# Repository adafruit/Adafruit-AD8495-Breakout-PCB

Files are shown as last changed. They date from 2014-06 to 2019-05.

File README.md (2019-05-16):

# PCB files for Adafruit Analog K-Type Thermocouple Amplifier AD8495 Breakout

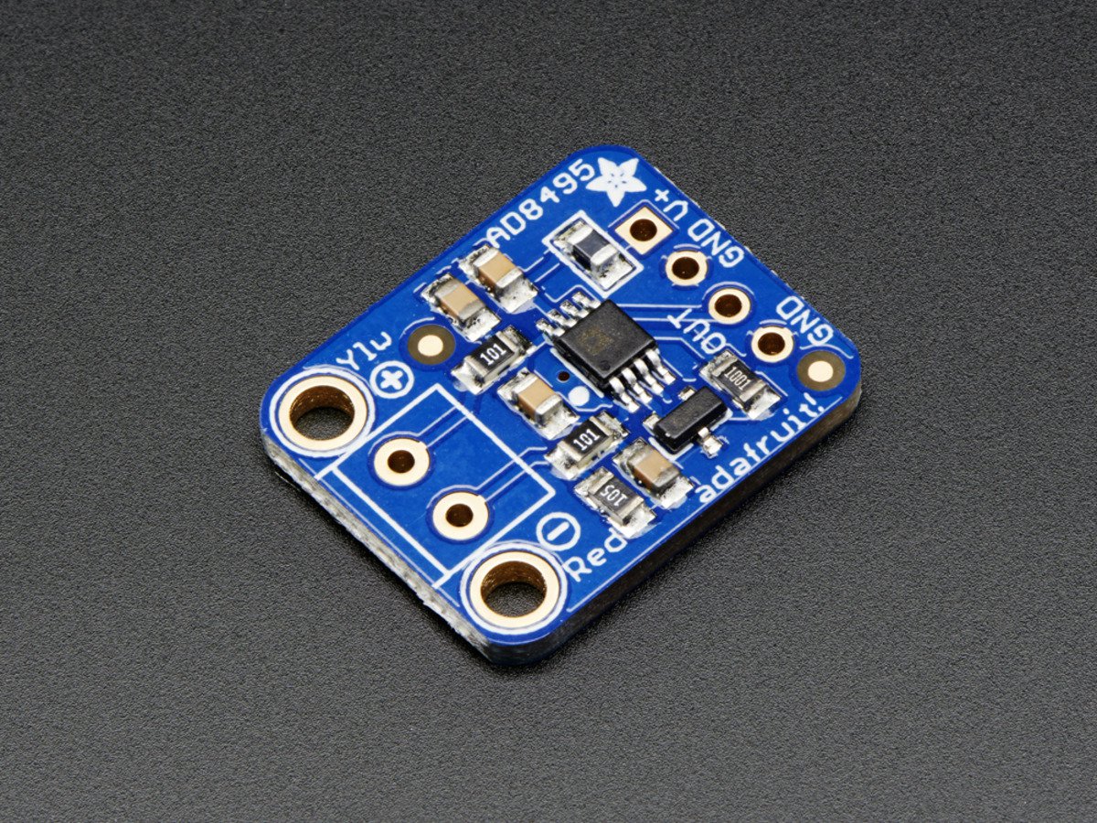
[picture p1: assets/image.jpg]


Thermocouples are very sensitive, requiring a good amplifier with a cold-compensation reference. We have a couple digital thermocouple amplifiers in the shop already from Maxim. Now we're happy to introduce an excellent analog-output amplifier. This is a very simple sensor to use, and if your microcontroller has analog input capability, you'll be ready to go really fast!

The AD8495 K-type thermocouple amplifier from Analog Devices is so easy to use, we documented the whole thing on the back of the tiny PCB. Power the board with 3-18VDC and measure the output voltage on the OUT pin. You can easily convert the voltage to temperature with the following equation: Temperature = (Vout - 1.25) / 0.005 V. So for example, if the voltage is 1.5VDC, the temperature is (1.5 - 1.25) / 0.005 = 50¡C

Each order comes with a 2 pin terminal block (for connecting to the thermocouple), a fully assembled PCB with the AD8495 + TLVH431 1.25V precision voltage reference, and pin header (to plug into any breadboard or perfboard). [Goes great with our 1m K-type thermocouple (not included)](http://www.adafruit.com/products/270). Not for use with any other kind of thermocouple, K type only!

- Works with any K type thermocouple
- Will not work with any other kind of thermocouple other than K type
- Easy to use analog output
- Temp range with 5V power: -250¡C to +750¡C output (0 to 5VDC) as long as the thermocouple can handle that range
- Temp range with 3.3V power: -250¡C to +410¡C output (0 to 3.3VDC) as long as the thermocouple can handle that range

__Note:__ The terminal blocks included with your product may be blue or black.

## License

Adafruit invests time and resources providing this open source design, 
please support Adafruit and open-source hardware by purchasing 
products from Adafruit!

Designed by Limor Fried/Ladyada for Adafruit Industries.
Creative Commons Attribution, Share-Alike license, check license.txt for more information
All text above must be included in any redistribution

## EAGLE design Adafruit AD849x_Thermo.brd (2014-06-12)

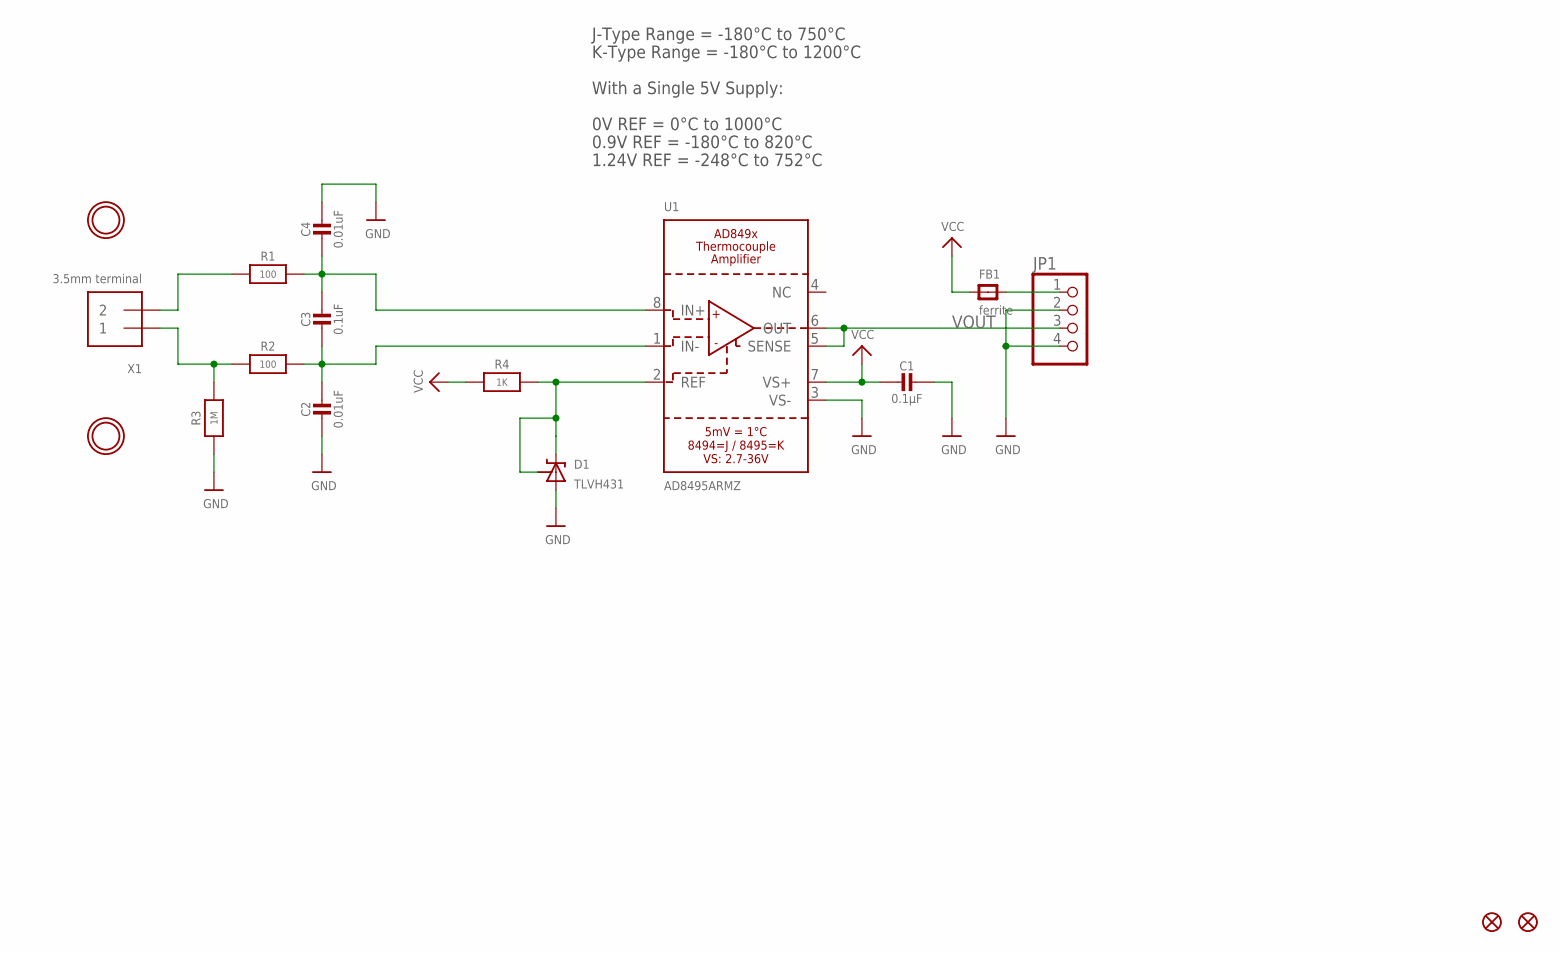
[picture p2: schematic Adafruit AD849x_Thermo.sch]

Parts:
C1: 0.1µF; 0805-NO
C2, C4: 0.01uF; 0805-NO
C3: 0.1uF; 0805-NO
D1: TLVH431; SOT23-R
FB1: ferrite; 0805
FID1, FID2: FIDUCIAL""; FIDUCIAL_1MM
JP1: HEADER-1X4ROUND; 1X04_ROUND
R1, R2: 100; 0805-NO
R3: 1M; 0805-NO
R4: 1K; 0805-NO
U1: AD8495ARMZ; MSOP8_0.65MM
U$11, U$12: MOUNTINGHOLE2.5; MOUNTINGHOLE_2.5_PLATED
X1: 3.5mm terminal; TERMBLOCK_1X2-3.5MM

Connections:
GND: C1.1, C2.2, C4.1, D1.3 (A), JP1.2, JP1.4, R3.1, U1.3 (VS-)
IN+: R1.1, X1.2
IN-: R2.1, R3.2, X1.1
unnamed: D1.1 (VREF), D1.2 (C), R4.2, U1.2 (REF)
unnamed: C3.1, C4.2, R1.2, U1.8 (IN+)
unnamed: C2.1, C3.2, R2.2, U1.1 (IN-)
unnamed: FB1.2, JP1.1
VCC: C1.2, FB1.1, R4.1, U1.7 (VS+)
VOUT: JP1.3, U1.5 (SENSE), U1.6 (OUT)

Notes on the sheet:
J-Type Range = -180°C to 750°C
K-Type Range = -180°C to 1200°C
With a Single 5V Supply:
1.24V REF = -248°C to 752°C
0.9V REF = -180°C to 820°C
0V REF = 0°C to 1000°C

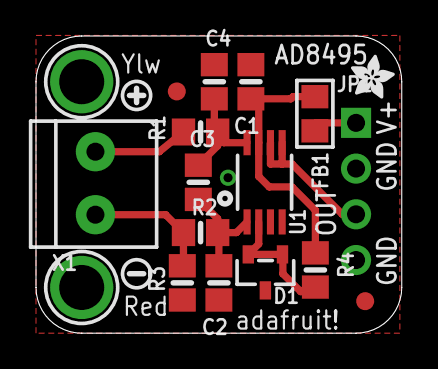
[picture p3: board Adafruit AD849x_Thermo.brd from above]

Board: 2 copper layers, 20.3 x 16.5 mm, 21 parts (1 on the bottom side), 9 nets.

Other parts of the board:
U$8: SYMBOL_PLUS
U$9: SYMBOL_MINUS
U$10: ADAFRUIT_2.5MM
U$13: ADAFRUIT_3.5MM

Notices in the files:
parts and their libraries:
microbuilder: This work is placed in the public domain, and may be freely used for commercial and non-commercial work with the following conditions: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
